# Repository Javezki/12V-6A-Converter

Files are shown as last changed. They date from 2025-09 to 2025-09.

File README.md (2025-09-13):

# About This Project

Hello everyone!  
This is a 12V/5V 8A adjustable buck converter I designed for a design team (96W Converter on a good day).

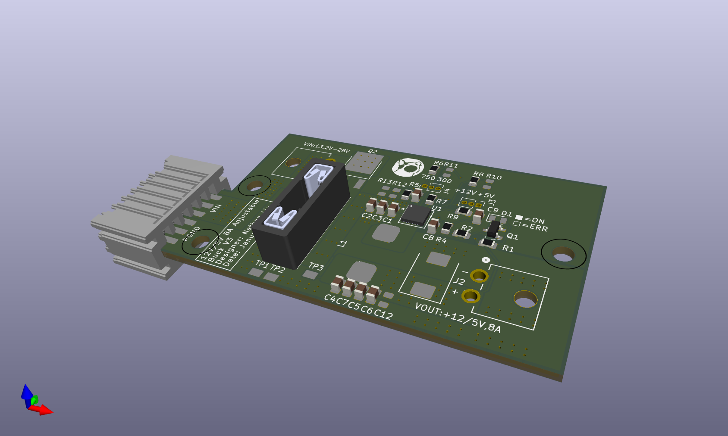
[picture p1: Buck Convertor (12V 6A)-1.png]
Buck Converter 3D Render


This version of the board is untested, but the core functionality (the converting) has been tested and it works pretty well.

## JLC Note

Every component on the board has a JLC#.  
You just need to solder your own automotive blade fuse holder (3557-2) and Molex Mini Fit Jrs (1726480102)—**though these connectors and the fuse holder can technically also be assembled by JLC, just at additional expense**.  
Approximate cost is ~40 CAD for 2 boards assembled, 2 week shipping, but could vary.

## Connector Note

It's a little tricky crimping those, but you can do it with a basic JST crimper.

## Other Functionality

- Automotive blade fuse and a PFET for reverse polarity protection present  
- Gold fingers for a slot card mount  
- Core chip: SIC438BED-T1-GE3 (large package, but JLC can assemble it with no problem)

# Tested Functionality

- 12V 6A works at 300 kHz switching frequency (Vin: 13.2V) with a thermal rise of about ~25°C  
- 5V 6A works at 750 kHz switching frequency (Vin: 13.2V) with a thermal rise of about ~10°C  
- Tests conducted with an electronic load, varying the current, and measuring temperature with a thermocouple  
- For higher voltage input: use 750 kHz for the 12V rail (calculate max duty cycle using the SIC438BED-T1-GE3 datasheet)

# Untested Functionality

- Reverse polarity protection was only simulated in MultiSim—untested in hardware due to costs  
- Jumpers for swapping 12V/5V and switching frequency are untested (just resistor swapping, so risk is minimal)  
- Board theoretically runs at 8A (no OCP trip at full load, chip rated 8A), but output ripple and full thermal capability aren't fully characterized. **Use at your own risk.**

# Things To Clean Up

- All JLC component footprint references are messed up because of a switch to KiCad 9  
- 3D models for all components need to be added eventually (on the todo list)  
- Better test pad layout is coming in a future revision  
- Replace the PFET with a proper reverse polarity charge pump IC for a high-side NFET (lower Rds(on), less heat)  
- Want different connectors? Let me know, or just mod the files yourself—they're on the page!

# Schematic

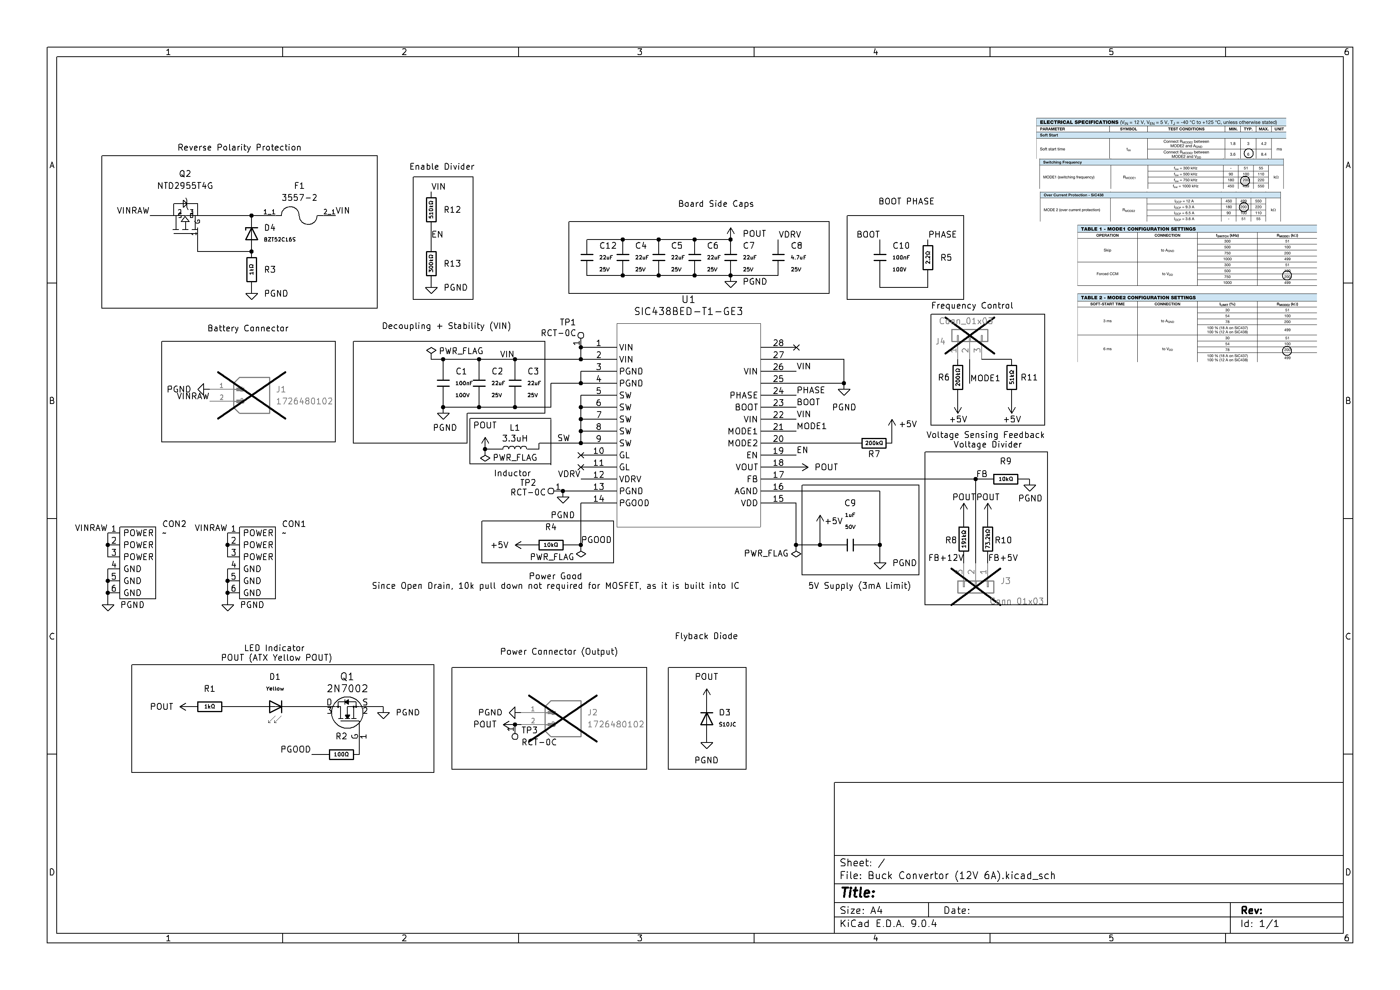
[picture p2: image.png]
Schematic Diagram


# Final Remarks

- 2-layer board build *might not work*—JLC assembly doesn't support this IC on 2 layer builds (success rate ~10%)  
- 4-layer assembly has been issue-free so far  
- If you want to fund more testing, DM me on Discord @javezki

Love y'all

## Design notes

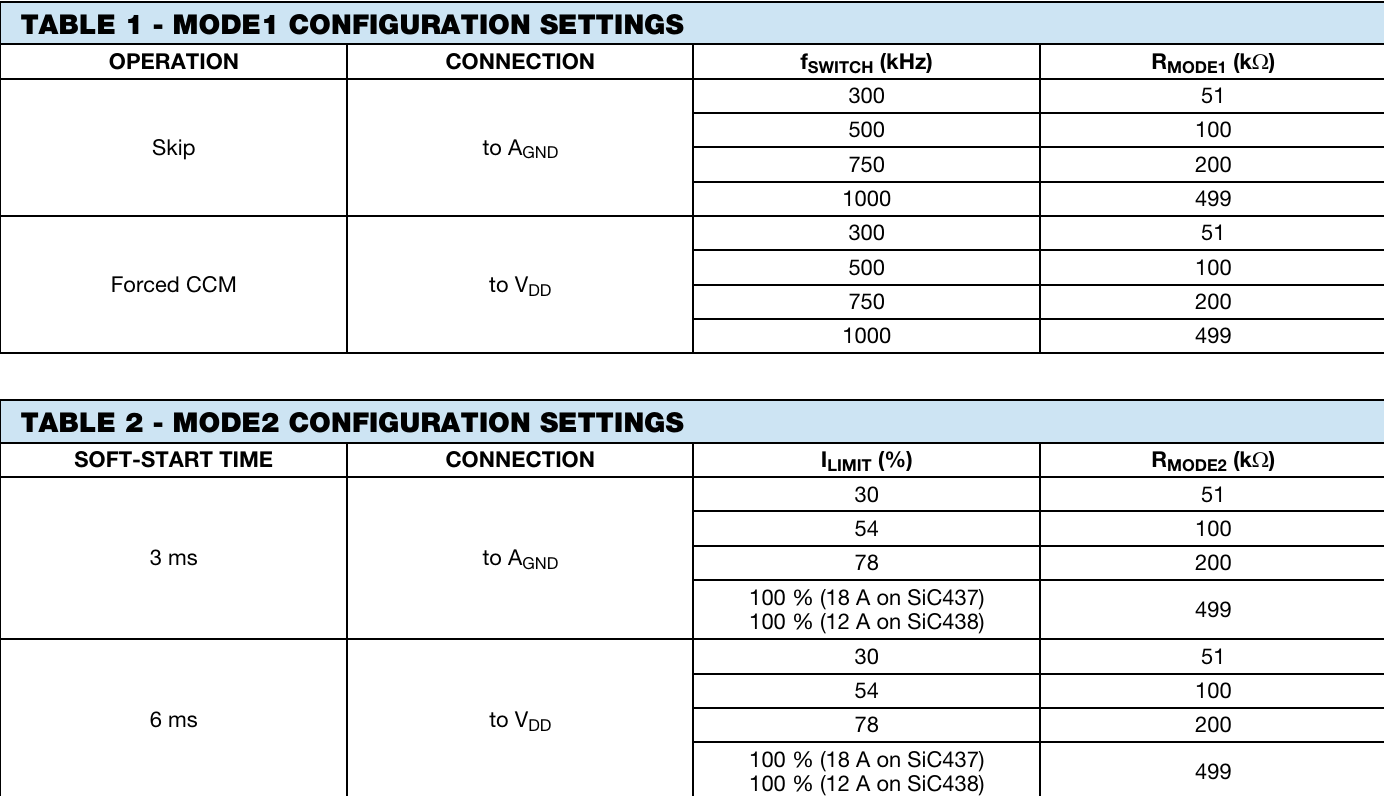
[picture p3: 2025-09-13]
MODES.png

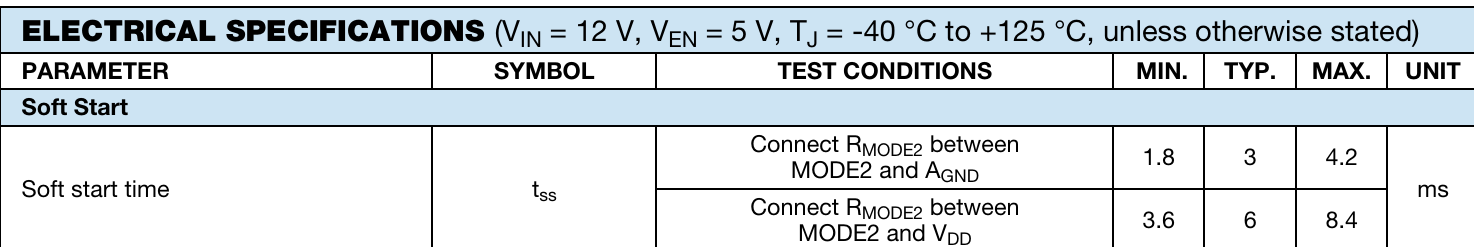
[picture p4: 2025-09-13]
SOFTSTART.png

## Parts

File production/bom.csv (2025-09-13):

Designator | Footprint | Quantity | Value | LCSC Part #
C1, C10 | C_0805 | 2 | 100nF | C28233
C12, C2, C3, C4, C5, C6, C7 | C_0805 | 7 | 22uF | C45783
C8 | C_0805 | 1 | 4.7uF | C1779
C9 | C_0805 | 1 | 1uF | C28323
CON1, CON2 | 6 Contact Gold Finger | 2 | ~
D1 | D_0805 | 1 | Yellow | C2296
D3 | D_SMC | 1 | S10JC | C18199110
D4 | D_SOD-323 | 1 | BZT52C16S | C19077449
F1 | FUSE_3557-2 | 1 | 3557-2
GND, VIN, VOUT | PROBE_PAD_0805 | 3 | RCT-0C | RCT-0C
L1 | ZEMS1040 | 1 | 3.3uH | C41415637
Q1 | SOT-23-3 | 1 | 2N7002 | C8545
Q2 | DPAK-369C_ONS | 1 | NTD2955T4G | C10663
R1, R3 | R_0805 | 2 | 1kΩ | C17513
R10 | R_0805 | 1 | 73.2kΩ | C17814
R11 | R_0805 | 1 | 51kΩ | C17737
R12 | R_0805 | 1 | 510kΩ | C17733
R13 | R_0805 | 1 | 300kΩ | C17616
R2 | R_0805 | 1 | 100Ω | C17408
R4, R9 | R_0805 | 2 | 10kΩ | C17414
R5 | R_0805 | 1 | 2.2Ω | C17521
R6, R7 | R_0805 | 2 | 200kΩ | C17539
R8 | R_0805 | 1 | 191kΩ | C17511
U1 | QFN_ED-T1-GE3_VIS | 1 | SIC438BED-T1-GE3 | C511430

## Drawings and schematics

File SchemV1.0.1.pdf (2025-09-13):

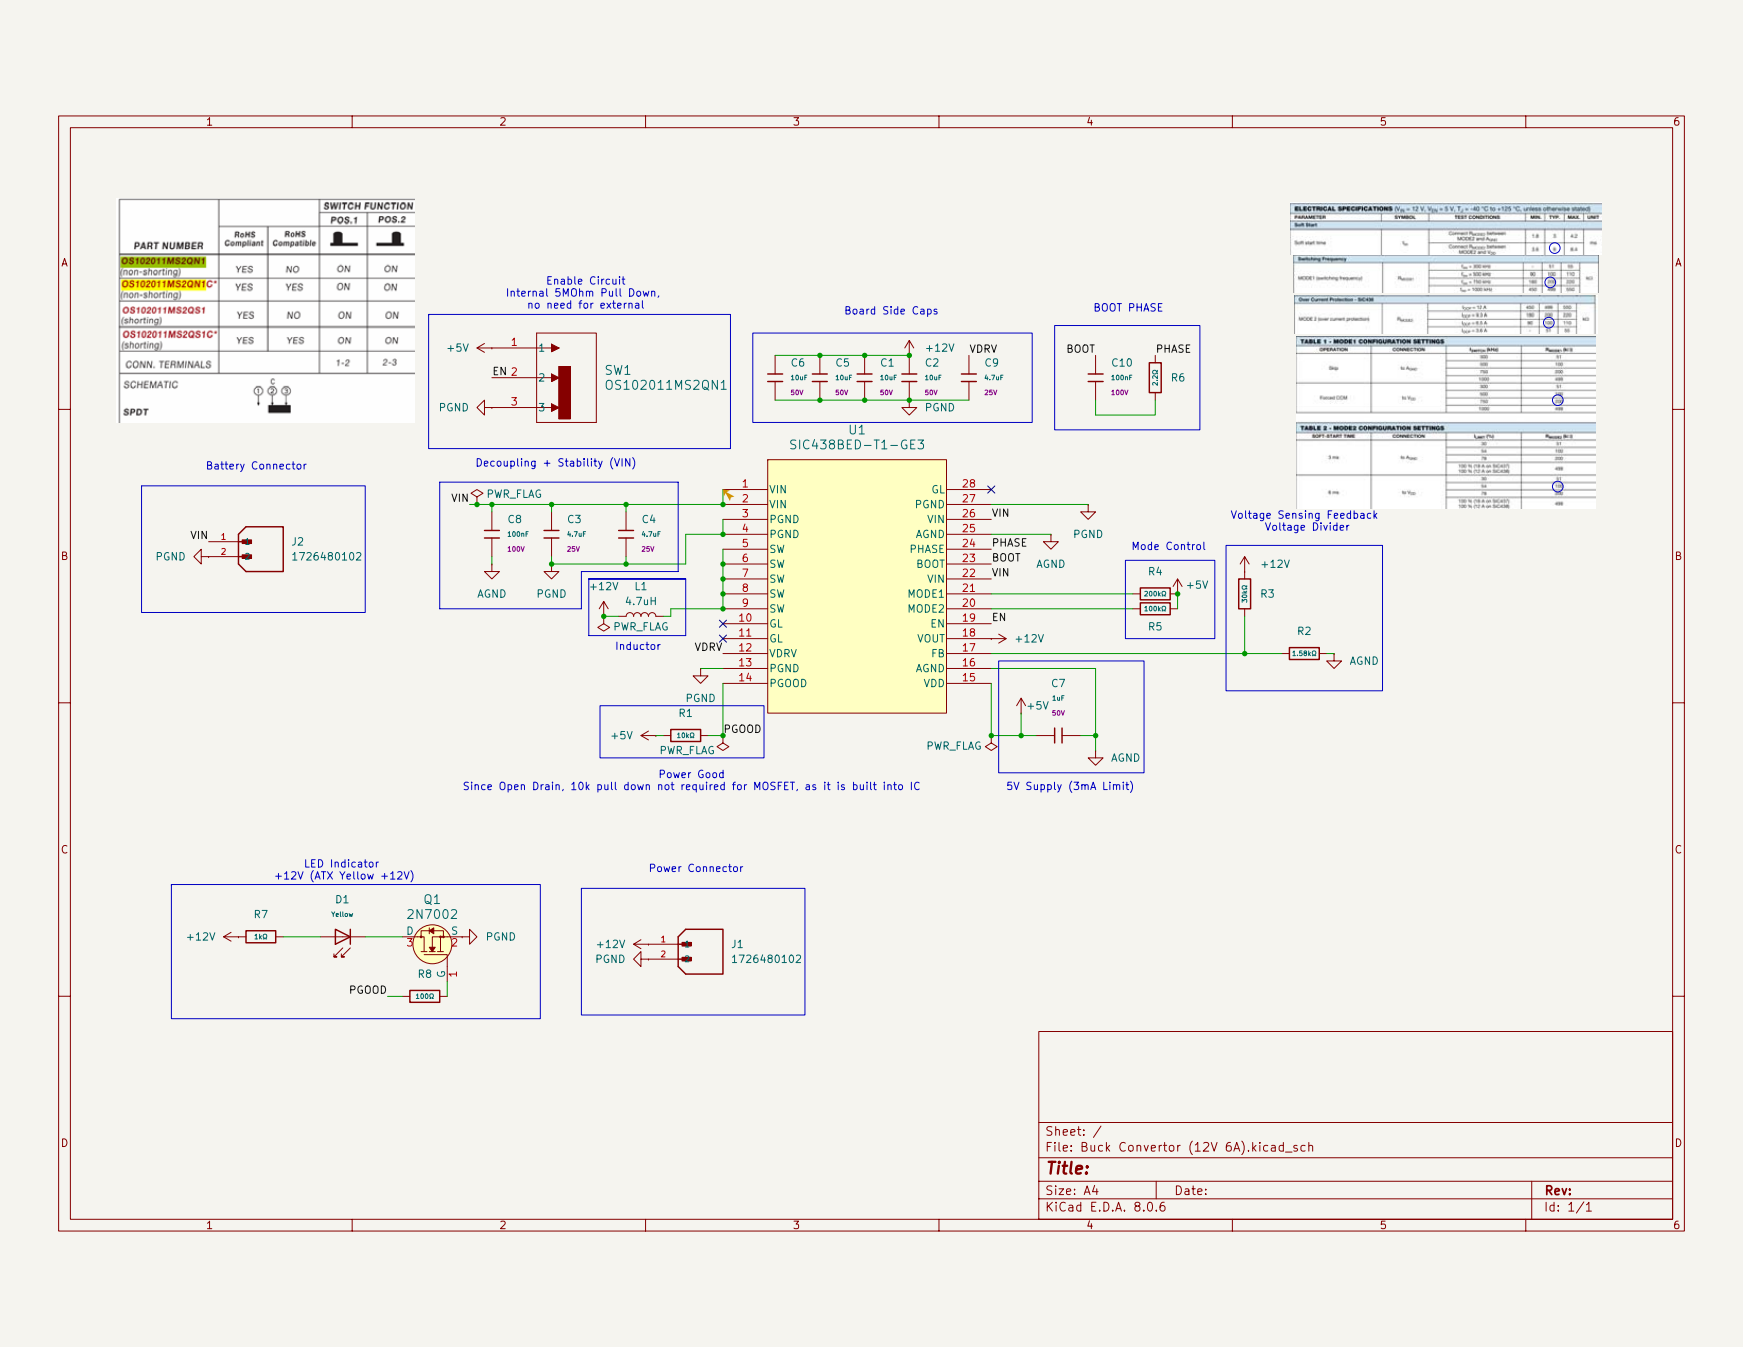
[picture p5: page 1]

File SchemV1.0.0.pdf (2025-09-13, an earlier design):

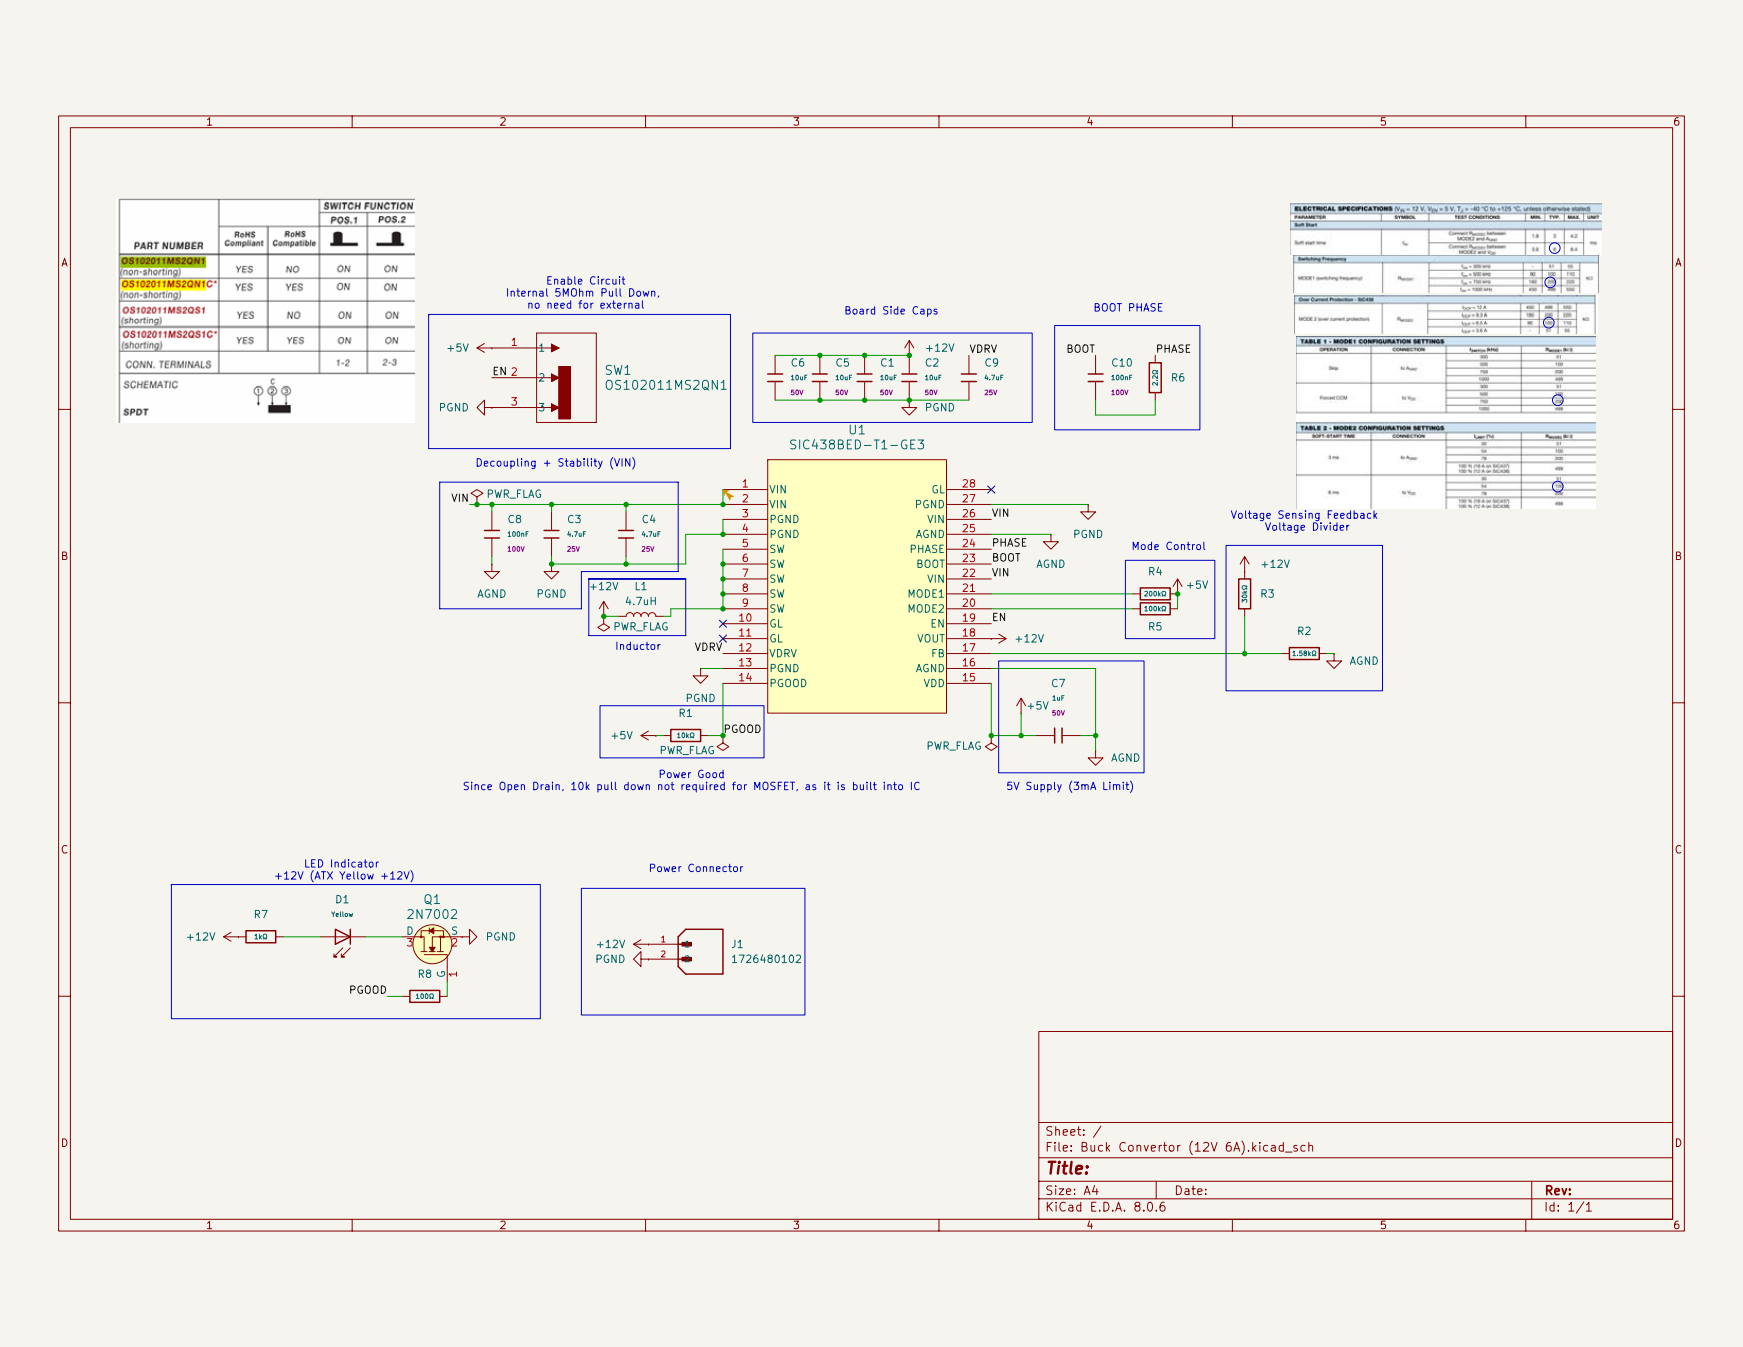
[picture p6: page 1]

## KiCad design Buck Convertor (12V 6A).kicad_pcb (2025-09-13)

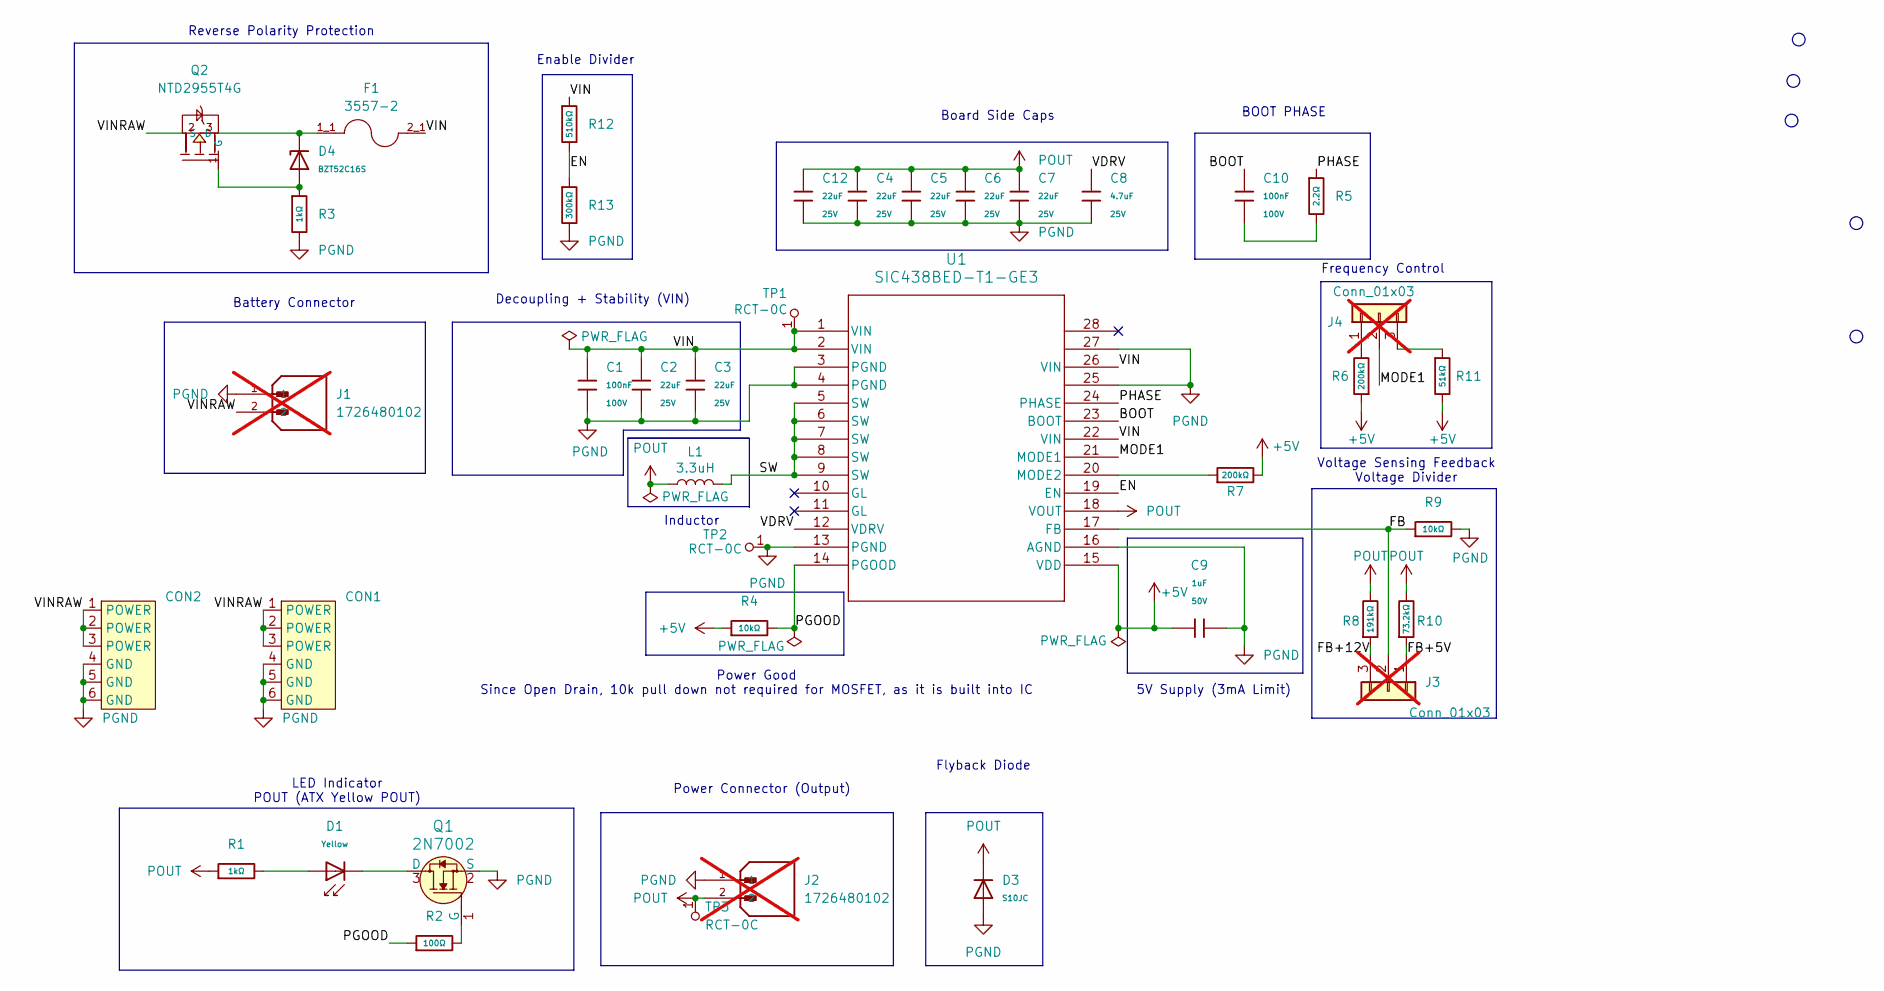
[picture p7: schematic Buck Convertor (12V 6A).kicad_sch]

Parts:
C1, C10: 100nF; C_0805; Voltage Rated 100V; Tolerance ±10%; Part CL21B104KCFNNNE; LCSC C28233
C2, C3, C4, C5, C6, C7, C12: 22uF; C_0805; Voltage Rated 25V; Tolerance ±20%; Part CL21A226MAQNNNE; LCSC C45783
C8: 4.7uF; C_0805; Voltage Rated 25V; Tolerance ±10%; Part CL21A475KAQNNNE; LCSC C1779
C9: 1uF; C_0805; Voltage Rated 50V; Tolerance ±10%; Part CL21B105KBFNNNE; LCSC C28323
CON1, CON2: 6 Contact Gold Finger
D1: Yellow; D_0805; Part KT-0805Y; LCSC C2296
D3: S10JC; D_SMC; Part S10JC; LCSC C18199110
D4: BZT52C16S; D_SOD-323; Zener Voltage (Range) 15.3V~17.1V; Zener Voltage (Nom) 16V; Part BZT52C16S; LCSC C19077449
F1: 3557-2; FUSE_3557-2; PARTREV D
J1, J2: 1726480102; CONN_SD-172648-0000_02_MOL; PARTREV A2; not fitted
J3, J4: Conn_01x03; PinHeader_1x03_P1.27mm_Vertical; not fitted
L1: 3.3uH; ZEMS1040; LCSC C41415637
Q1: 2N7002; SOT-23-3; MPN 2N7002; Digi-Key_PN 2N7002NCT-ND
Q2: NTD2955T4G; TO-252-2_L6.6-W6.1-P4.57-LS9.9-TL-CW; LCSC C10663
R1, R3: 1kΩ; R_0805; Overload Voltage (Max) 150V; Tolerance ±1%; Part 0805W8F1001T5E; LCSC C17513
R2: 100Ω; R_0805; Overload Voltage (Max) 150V; Tolerance ±1%; Part 0805W8F1000T5E; LCSC C17408
R4, R9: 10kΩ; R_0805; Overload Voltage (Max) 150V; Tolerance ±1%; Part 0805W8F1002T5E; LCSC C17414
R5: 2.2Ω; R_0805; Overload Voltage (Max) 150V; Tolerance ±1%; Part 0805W8F220KT5E; LCSC C17521
R6, R7: 200kΩ; R_0805; Overload Voltage (Max) 150V; Tolerance ±1%; Part 0805W8F2003T5E; LCSC C17539
R8: 191kΩ; R_0805; LCSC C17511
R10: 73.2kΩ; R_0805; LCSC C17814
R11: 51kΩ; R_0805; Overload Voltage (Max) 150V; Tolerance ±1%; Part 0805W8F5102T5E; LCSC C17737
R12: 510kΩ; R_0805; Overload Voltage (Max) 150V; Tolerance ±1%; Part 0805W8F5103T5E; LCSC C17733
R13: 300kΩ; R_0805; Overload Voltage (Max) 150V; Tolerance ±1%; Part 0805W8F3003T5E; LCSC C17616
TP1, TP2, TP3: RCT-0C; PROBE_PAD_0805; MPN RCT-0C; Digi-Key_PN A106144CT-ND
U1: SIC438BED-T1-GE3; QFN_ED-T1-GE3_VIS; LCSC C511430

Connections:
+5V: C9.1, R4.1, R6.1, R7.2, R11.2, U1.15 (VDD)
/BOOT: C10.2, U1.23 (BOOT)
/EN: R12.2, R13.1, U1.19 (EN)
/FB: J3.2, R9.1, U1.17 (FB)
/FB+5V: J3.1, R10.2
/FB+12V: J3.3, R8.2
/MODE1: J4.2, U1.21 (MODE1)
/PGOOD: R2.1, R4.2, U1.14 (PGOOD)
/PHASE: R5.1, U1.24 (PHASE)
/SW: L1.2, U1.5 (SW), U1.6 (SW), U1.7 (SW), U1.8 (SW), U1.9 (SW)
/VDRV: C8.1, U1.12 (VDRV)
/VIN: C1.1, C2.1, C3.1, F1.2_1, R12.1, TP1.1, U1.1 (VIN), U1.2 (VIN), U1.22 (VIN), U1.26 (VIN)
/VINRAW: CON1.1 (POWER), CON1.2 (POWER), CON1.3 (POWER), CON2.1 (POWER), CON2.2 (POWER), CON2.3 (POWER), J1.2, Q2.2 (D)
unnamed: C10.1, R5.2
unnamed: D1.2, R1.2
unnamed: J4.1, R6.2
unnamed: J4.3, R11.1
unnamed: D1.1, Q1.3 (D)
unnamed: Q1.1 (G), R2.2
unnamed: D4.2, Q2.1 (G), R3.1
unnamed: D4.1, F1.1_1, Q2.3 (S)
unnamed: R7.1, U1.20 (MODE2)
PGND: C1.2, C2.2, C3.2, C4.2, C5.2, C6.2, C7.2, C8.2, C9.2, C12.2, CON1.4 (GND), CON1.5 (GND), CON1.6 (GND), CON2.4 (GND), CON2.5 (GND), CON2.6 (GND), D3.2, J1.1, J2.1, Q1.2 (S), R3.2, R9.2, R13.2, TP2.1, U1.3 (PGND), U1.4 (PGND), U1.13 (PGND), U1.16 (AGND), U1.25, U1.27
POUT: C4.1, C5.1, C6.1, C7.1, C12.1, D3.1, J2.2, L1.1, R1.1, R8.1, R10.1, TP3.1, U1.18 (VOUT)

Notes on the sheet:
Battery Connector
Power Good Since Open Drain, 10k pull down not required for MOSFET, as it is built into IC
Board Side Caps
5V Supply (3mA Limit)
Inductor
Decoupling + Stability (VIN)
LED Indicator POUT (ATX Yellow POUT)
Frequency Control
Reverse Polarity Protection
Power Connector (Output)
BOOT PHASE
Voltage Sensing Feedback Voltage Divider
Flyback Diode
Enable Divider

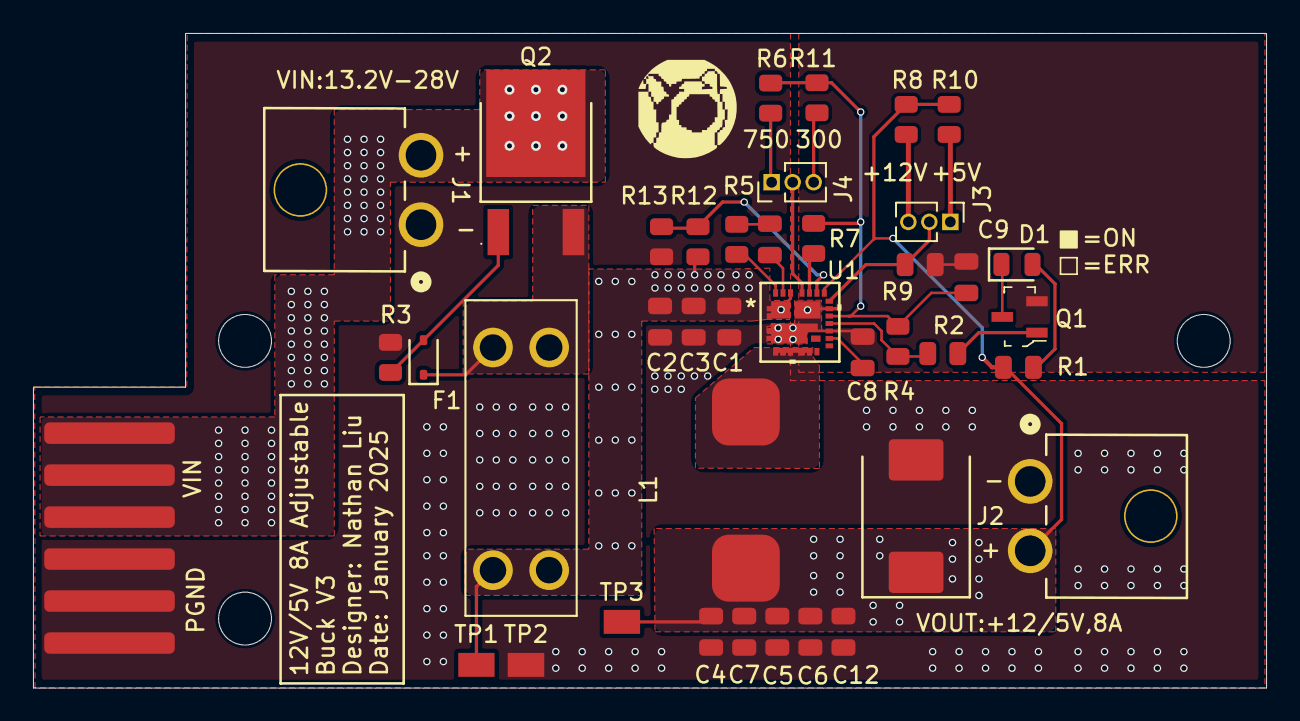
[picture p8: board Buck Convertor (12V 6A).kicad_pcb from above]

Board: 4 copper layers, 74.6 x 39.6 mm, 41 parts (1 on the bottom side), 24 nets.

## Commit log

2025-09-13 Initial Commit
    All files of 12V/5V 8A buck converter project available for JLCPCB
    [3557-2.step, Buck Convertor (12V 6A).kicad_pcb, Buck Convertor (12V 6A).kicad_sch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]
2025-09-13 Fixed PFET being wrong size
    [3557-2.step, Buck Convertor (12V 6A).kicad_pcb, Buck Convertor (12V 6A).kicad_sch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]
2025-09-13 Update README with JLC and connector notes
    Added notes about JLC components, connectors, and other functionalities.
